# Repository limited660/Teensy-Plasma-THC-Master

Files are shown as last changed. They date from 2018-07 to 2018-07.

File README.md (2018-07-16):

# Teensy Plasma THC Master

Loop
- Teensy 3.1
  - CPU Speed : 96MHz
  - Optimize : Fastest with LTO
  - Loop Time : 5.5 microsecond average
  - Cost : $19.80 (7/15/2018)
- Teensy LC
  - CPU Speed : 48MHz
  - Optimize : Faster with LTO
  - Loop Time : 15.7 microsecond average
  - Cost : $11.65 (7/15/2018)

Screen
- RepRap Smart Controller (4x20 with Push Button Encoder)

Button
- One Press = Swap between Tip Target/Hysteresis & save value if changed
- Double Press = Recalls highlighted value from EEPROM
- Hold(Editing Value) = Saves highlighted value to EEPROM, this value is restored on power up and using Double Press
- Hold(Not Editing Value) = Disables output and voltage comparisions, still prints current tip voltage to screen (tip voltage is always printed with small delay) 

Encoder
- Change highlighted value

Frequency Counter
- THCAD should be set to F/1
- Gate interval of 10 milliseconds
- Change mapfloat in Loop to match numbers provided on THCAD

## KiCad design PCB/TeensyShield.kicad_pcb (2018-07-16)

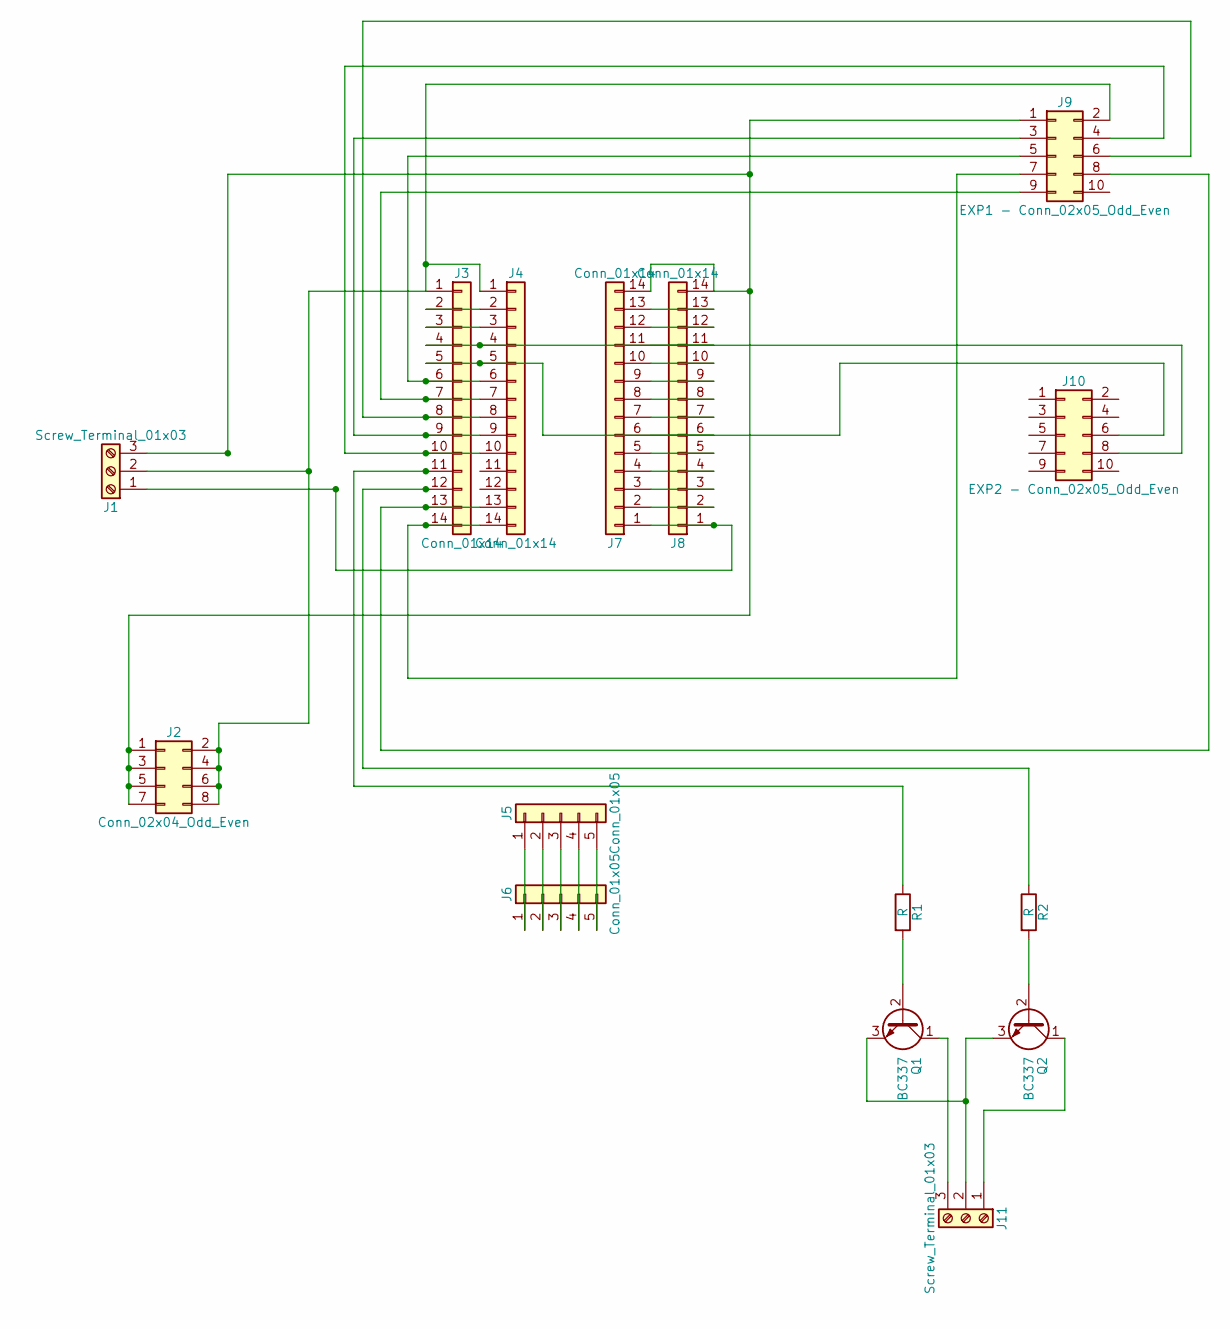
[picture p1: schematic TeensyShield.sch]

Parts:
J1, J11: Screw_Terminal_01x03; TerminalBlock_Phoenix_MPT-2.54mm_3pol
J2: Conn_02x04_Odd_Even; Pin_Header_Angled_2x04_Pitch2.54mm
J3, J4, J7, J8: Conn_01x14; Pin_Header_Straight_1x14_Pitch2.54mm
J5, J6: Conn_01x05; Pin_Header_Straight_1x05_Pitch2.54mm
J9: EXP1 - Conn_02x05_Odd_Even; Pin_Header_Straight_2x05_Pitch2.54mm
J10: EXP2 - Conn_02x05_Odd_Even; Pin_Header_Straight_2x05_Pitch2.54mm
Q1, Q2: BC337; TO-92_Molded_Narrow
R1, R2: R; R_Axial_DIN0207_L6.3mm_D2.5mm_P10.16mm_Horizontal

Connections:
unnamed: J1.1, J7.1, J8.1
unnamed: J1.2, J2.2, J2.4, J2.6, J2.8, J3.1, J4.1, J9.2
unnamed: J1.3, J2.1, J2.3, J2.5, J2.7, J7.14, J8.14, J9.1
unnamed: J3.2, J4.2
unnamed: J3.3, J4.3
unnamed: J3.6, J4.6, J9.5
unnamed: J3.7, J4.7, J9.9
unnamed: J3.8, J4.8, J9.6
unnamed: J3.9, J4.9, J9.3
unnamed: J3.10, J4.10, J9.4
unnamed: J3.11, R1.1
unnamed: J3.12, R2.1
unnamed: J3.13, J4.13, J9.8
unnamed: J3.14, J4.14, J9.7
unnamed: J5.1, J6.1
unnamed: J5.2, J6.2
unnamed: J5.3, J6.3
unnamed: J5.4, J6.4
unnamed: J5.5, J6.5
unnamed: J7.2, J8.2
unnamed: J7.3, J8.3
unnamed: J7.4, J8.4
unnamed: J7.5, J8.5
unnamed: J7.6, J8.6
unnamed: J7.7, J8.7
unnamed: J7.8, J8.8
unnamed: J7.9, J8.9
unnamed: J7.10, J8.10
unnamed: J7.11, J8.11
unnamed: J7.12, J8.12
unnamed: J7.13, J8.13
unnamed: J3.5, J4.5, J10.6
unnamed: J3.4, J4.4, J10.8
unnamed: J11.1, Q2.1 (C)
unnamed: J11.2, Q1.3 (E), Q2.3 (E)
unnamed: J11.3, Q1.1 (C)
unnamed: Q1.2 (B), R1.2
unnamed: Q2.2 (B), R2.2

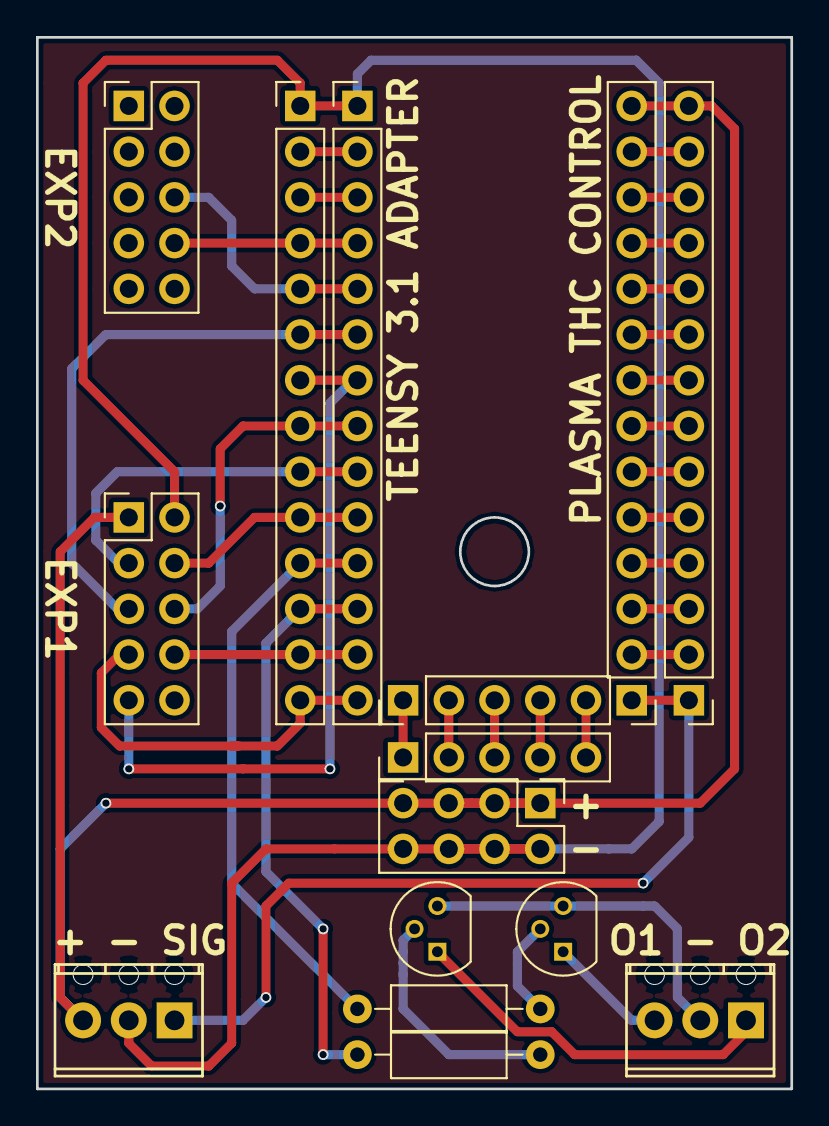
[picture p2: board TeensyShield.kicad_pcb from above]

Board: 2 copper layers, 41.9 x 58.4 mm, 15 parts (0 on the bottom side), 38 nets.

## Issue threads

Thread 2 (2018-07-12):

Height control fails to respond on fast voltage drop

limited660, 2018-07-12:
Voltage dropping below 100 disables outputs from Teensy causing torch crashes as head is no longer moving.  Placing a delay after moving to cut height and before allowed the voltage to stabilize enough for the Teensy to start outputting commands.  Hypertherm recommends 96v when cutting 12 Gauge with Powermax30 consumables at 30 amps which is the lowest found in the Powermax45 manual.

This may also require a rewrite on LCD and encoder printing to handle values less than 3 digits, code should be similar to Hysteresis printing.

Ideas:
Unlock floor to 50-75v?
Allow output 25-50v below/above target rather than hard floor/ceiling?

limited660, 2018-07-15:
Fixed in https://github.com/limited660/Teensy-Plasma-THC-Master/commit/e283efdac306a5a05f02b09cd5d4dcc160565763

Closed 2018-07-15.

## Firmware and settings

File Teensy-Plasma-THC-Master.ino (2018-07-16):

//Libraries
#include <FreqCount.h>
  //https://github.com/PaulStoffregen/FreqCount
#include <OneButton.h>
  //https://github.com/mathertel/OneButton
#include <LiquidCrystal.h>
#include <EEPROM.h>

//Floating Map Function
float mapfloat(float x, float in_min, float in_max, float out_min, float out_max)
{
  return (x - in_min) * (out_max - out_min) / (in_max - in_min) + out_min;
}

//THC A-D Input must be on pin 5 on Uno or pin 13 on Teensy 3.1
//OneButton pin needs swapped if changing between Uno and Teensy, pin 13 on Uno or pin 5 on Teensy 3.1

  //LCD Pins
  #define LCD_RS      12
  #define LCD_EN      11
  #define LCD_D4       6
  #define LCD_D5       4
  #define LCD_D6       8
  #define LCD_D7       7
  #define LCD_CHARS   20
  #define LCD_LINES    4

  //Encoder Pins
  int encoderPinA = 3;
  int encoderPinB = 2;

  //New OneButton
  OneButton button(5,true);

//LCD Pin Setup and Custom Character
LiquidCrystal lcd(LCD_RS, LCD_EN, LCD_D4, LCD_D5, LCD_D6, LCD_D7);
uint8_t testChar[8] = {0xff,0xff,0xff,0xff,0xff,0xff,0xff,0xff}; // Custom char


//Variable Setup
int16_t TargetVal, EncoderValue, TipEncoder, HysEncoder, TargetHys, PrevEncoder;
bool flash, thcStatus;
unsigned long startMillis, torchMillis, currentMillis;
float TorchVal, PrevTorch;
int ButtonPress, tUp, tDown, tOff, minVolt, maxVolt, lastEncoded;

void setup() {

  FreqCount.begin(10);
  
  //Variable setup
  flash = false;
  lastEncoded = 0;
  ButtonPress = 0;
  tUp = 0; 
  tDown = 0; 
  tOff = 0; 
  minVolt = 25;
  maxVolt = 175;
  
  
  TargetVal = EEPROM.read(0);
  TipEncoder = TargetVal;
  TargetHys = EEPROM.read(1);
  HysEncoder = TargetHys;

  thcStatus = EEPROM.read(2);
  
  EncoderValue = TipEncoder; //Start with TipEncoder since it is first in button statement
  
  //Timer setup
  startMillis = millis();
  torchMillis = millis();
  
  
  //Button setup
  button.attachClick(ClickFunction); //Create Click function for button
  button.attachDoubleClick(DoubleClickFunction); //Create Double Click function for button
  button.attachLongPressStart(HoldFunction); //Create Hold function for button
  
  
  //Output setup
  pinMode(9, OUTPUT); //Torch Up output
  digitalWrite(9, LOW); //Turn output off    
  pinMode(10, OUTPUT); //Torch Down output
  digitalWrite(10, LOW); //Turn output off
  
  
  //LCD Setup
  lcd.begin(LCD_CHARS, LCD_LINES);
  lcd.clear();
  lcd.createChar(0, testChar); //Create custom full block char and send to LCD
  
  
  //LCD startup message
  lcd.setCursor(0,0);
  lcd.print("CNC Plasma Torch");
  lcd.setCursor(0,1);
  lcd.print("Height Control");
  lcd.setCursor(0,2);
  lcd.print("Created by");
  lcd.setCursor(0,3);
  lcd.print("Tyler Bennett");
  delay(5000);
  lcd.clear();
  
  
  //LCD text setup
  lcd.setCursor(0, 0);
  lcd.print("Tip Voltage:");
  lcd.setCursor(13,0);
  lcd.print("-----");
  lcd.setCursor(0, 1);
  lcd.print("Tip Target:"); 
  lcd.setCursor(0, 2);
  lcd.print("Hysteresis:");
  if(thcStatus){
    lcd.setCursor(12, 1);
    lcd.print(TargetVal); //Write initial TargetVal, updated by button press
    lcd.setCursor(12, 2);
    lcd.print(TargetHys); //Write initial TargetHys, updated by button press
  }
  else {
    lcd.setCursor(12, 1);
    lcd.print("        ");
    lcd.setCursor(12, 2);
    lcd.print("        ");
    lcd.setCursor(12, 1);
    lcd.print("DISABLED");
    lcd.setCursor(12, 2);
    lcd.print("DISABLED");
  }
  lcd.setCursor(0,3);
  lcd.print("UP:");
  lcd.setCursor(6,3);
  lcd.print("Down:");
  lcd.setCursor(14,3);
  lcd.print("Off:");
  
  
  //Encoder Setup
  pinMode(encoderPinA, INPUT_PULLUP); 
  pinMode(encoderPinB, INPUT_PULLUP);
  
  //get starting position
  int lastMSB = digitalRead(encoderPinA);
  int lastLSB = digitalRead(encoderPinB);
  
  //let start be lastEncoded so will index on first click
  lastEncoded = (lastMSB << 1) |lastLSB;

}//Setup

void loop() {  

  currentMillis = millis(); //Grab current loop time, millis used to not delay code execution
  
  button.tick(); //Check button for input
  
  if (FreqCount.available()) {
    TorchVal = mapfloat(FreqCount.read(), 1197, 9265, 0.0, 10.0); //Mapping information from Mesa THCAD
    TorchVal = TorchVal*50; 
    if (currentMillis - torchMillis >= 250 && TorchVal != PrevTorch) { //Delay printing of TorchVal to make it easier to read and dont print if same as previous value
      torchMillis = millis();
      PrevTorch = TorchVal;
      lcd.setCursor(12,0);
      lcd.print("        ");
      lcd.setCursor(13,0);
      if (TorchVal < minVolt){ //Disable display below minVolt to signify no action
        lcd.print("------");
      } //End If
      else if (TorchVal > maxVolt){ //Disable display above maxVolt to signify no action
        lcd.setCursor(12,0);
        lcd.print("OVER-MAX");
      } //End If
      else{
        lcd.print(TorchVal,1);
      } //End Else
    } //End If
  } //End If
  
  if (ButtonPress == 1 || ButtonPress == 2) {
    int MSB = digitalRead(encoderPinA); //MSB = most significant bit
    int LSB = digitalRead(encoderPinB); //LSB = least significant bit
    int encoded = (MSB << 1) |LSB; //converting the 2 pin value to single number
    int sum  = (lastEncoded << 2) | encoded; //adding it to the previous encoded value
    if(sum == 0b1101 || sum == 0b0010)EncoderValue ++;  
    if(sum == 0b1110 || sum == 0b0001)EncoderValue --;
    lastEncoded = encoded; //store this value for next time
  } //End If
  
  if (ButtonPress == 1) {
    if(EncoderValue != TargetVal){
      if(EncoderValue <= minVolt)EncoderValue = minVolt; //Don't let EncoderValue below minVolt
      if(EncoderValue >= maxVolt)EncoderValue = maxVolt; //Don't let EncoderValue above maxVolt
      if(EncoderValue != PrevEncoder) {
        lcd.setCursor(12, 1);
        lcd.print("        ");
        lcd.setCursor(12, 1);
        lcd.print(EncoderValue);
        PrevEncoder = EncoderValue;
      } //End If
    } //End If
    else if(EncoderValue != PrevEncoder){
      lcd.setCursor(12, 1);
      lcd.print("        ");
      lcd.setCursor(12, 1);
      lcd.print(EncoderValue);
      PrevEncoder = EncoderValue;
    } //End Else If
    
    //Begin code for flashing Tip Target text
    if (currentMillis - startMillis >= 500 && flash) { //Hide Tip Target text
      startMillis = millis();
      lcd.setCursor(0, 1);
      lcd.print("           ");
      flash = false;
    } //End If
    else if(currentMillis - startMillis >= 300 && !flash) { //Show Tip Target text
      startMillis = millis();
      lcd.setCursor(0, 1);
      lcd.print("Tip Target:");
      flash = true;
    } //End Else If
  } //End If
  else if (ButtonPress ==2){
    if(EncoderValue != TargetHys){
      if(EncoderValue <= 0)EncoderValue = 0; //Don't let EncoderValue below 0
      if(EncoderValue >= 15)EncoderValue = 15; //Don't let EncoderValue above 15
      if(EncoderValue != PrevEncoder) {
        lcd.setCursor(12, 2);
        lcd.print("        ");
        lcd.setCursor(12, 2);
        lcd.print(EncoderValue);
        PrevEncoder = EncoderValue;
      } //End If
    } //End If
    else if(EncoderValue != PrevEncoder) {
      lcd.setCursor(12, 2);
      lcd.print("        ");
      lcd.setCursor(12, 2);
      lcd.print(EncoderValue);
      PrevEncoder = EncoderValue;
    } //End Else If
    
    //Begin code for flashing Tip Target text
    if (currentMillis - startMillis >= 500 && flash) { //Hide Tip Target text
      startMillis = millis();
      lcd.setCursor(0, 2);
      lcd.print("           ");
      flash = false;
    } //End If
    else if(currentMillis - startMillis >= 300 && !flash) { //Show Tip Target text
      startMillis = millis();
      lcd.setCursor(0, 2);
      lcd.print("Hysteresis:");
      flash = true;
    } //End Else If
  } //End Else If
  
  //Code for moving torch based on tip value compared to requested value, add outputs here.
  if(TorchVal < (TargetVal - TargetHys) && TorchVal >= minVolt && thcStatus){ //Voltage too low, raise torch     
    if(tUp != 1) { //Test if output has already been set
      //Turn Down off, Up on
      digitalWrite(10, LOW);       
      digitalWrite(9, HIGH);  
      tUp = 1; 
      tDown = 0; 
      tOff = 0; 
      lcd.setCursor(4,3);
      lcd.print((char)0);
      //Clear Other Squares
      lcd.setCursor(12,3);
      lcd.print(" ");
      lcd.setCursor(19,3);
      lcd.print(" ");
    } //End If
  } //End If
  else if(TorchVal > (TargetVal + TargetHys) && TorchVal <= maxVolt && thcStatus){ //Voltage too high, lower torch
    if(tDown != 1) { //Test if output has already been set
      //Turn Up off, Down on
      digitalWrite(9, LOW);       
      digitalWrite(10, HIGH); 
      tUp = 0; 
      tDown = 1; 
      tOff = 0; 
      lcd.setCursor(12,3);
      lcd.print((char)0);
      //Clear Other Squares
      lcd.setCursor(19,3);
      lcd.print(" ");
      lcd.setCursor(4,3);
      lcd.print(" ");
    } //End If
  } //End Else If
  else { //Voltage Stable - Outputs Off
    if(tOff != 1) { //Test if output has already been set
      //Turn both outputs off
      digitalWrite(10, LOW);       
      digitalWrite(9, LOW); 
      tUp = 0; 
      tDown = 0; 
      tOff = 1; 
      lcd.setCursor(19,3);
      lcd.print((char)0);
      //Clear Other Squares
      lcd.setCursor(4,3);
      lcd.print(" ");
      lcd.setCursor(12,3);
      lcd.print(" ");
    } //End If
  } //End Else

}// Loop

  
void ClickFunction() { //Runs on single click of encoder button
  if(thcStatus){
    if(ButtonPress == 3)ButtonPress = 0; //Loop back around
    
    if(ButtonPress == 1){
      if(EncoderValue != TargetVal){//Encoder was changed, 
        TargetVal = EncoderValue;
        TipEncoder = EncoderValue;
        ButtonPress = -1;
        lcd.setCursor(12, 1);
        lcd.print("        ");
        lcd.setCursor(12, 1);
        lcd.print(TargetVal);
      }
      else {
        EncoderValue = HysEncoder; //Swap to HysEncoder so it is ready for next button press
        lcd.setCursor(12, 1);
        lcd.print("        ");
        lcd.setCursor(12, 1);
        lcd.print(TargetVal);
      }
    }
    
    if(ButtonPress == 2){   
      if(EncoderValue != TargetHys){
        TargetHys = EncoderValue;
        HysEncoder = EncoderValue;
        ButtonPress = -1;
        lcd.setCursor(12, 2);
        lcd.print("        ");
        lcd.setCursor(12, 2);
        lcd.print(TargetHys);
      }
      else {
        lcd.setCursor(12, 2);
        lcd.print("        ");
        lcd.setCursor(12, 2);
        lcd.print(TargetHys);
      }
      EncoderValue = TipEncoder;
    }
    //Write back to LCD in case lines were blank when exiting flashing statement
    lcd.setCursor(0, 1);
    lcd.print("Tip Target:");
    lcd.setCursor(0, 2);
    lcd.print("Hysteresis:");
    ButtonPress++;
  }
}

void DoubleClickFunction() { //Runs on double click of encoder button
  if(ButtonPress == 1) {
    EncoderValue = EEPROM.read(0);
    lcd.setCursor(12, 1);
    lcd.print("        ");
    lcd.setCursor(12, 1);
    lcd.print(EncoderValue);
  }
  if(ButtonPress == 2) {
    EncoderValue = EEPROM.read(1);
    lcd.setCursor(12, 2);
    lcd.print("        ");
    lcd.setCursor(12, 2);
    lcd.print(EncoderValue);
  }
}

void HoldFunction() { //Runs on hold of encoder button
  if(ButtonPress == 1) {
    EEPROM.write(0, TargetVal); //Write current TargetVal to EEPROM 0
    lcd.setCursor(12, 1);
    lcd.print("        ");
    lcd.setCursor(12, 1);
    lcd.print("SAVED");
  }
  else if(ButtonPress == 2) {
    EEPROM.write(1, TargetHys); //Write current TargetHys to EEPROM 1
    lcd.setCursor(12, 2);
    lcd.print("        ");
    lcd.setCursor(12, 2);
    lcd.print("SAVED");
  }
  else {
    if (thcStatus) {
      thcStatus = false;
      lcd.setCursor(12, 1);
      lcd.print("        ");
      lcd.setCursor(12, 2);
      lcd.print("        ");
      lcd.setCursor(12, 1);
      lcd.print("DISABLED");
      lcd.setCursor(12, 2);
      lcd.print("DISABLED");
      EEPROM.write(2, thcStatus); //Write current thcStatus to EEPROM 2
    }
    else{
      thcStatus = true;
      lcd.setCursor(12, 1);
      lcd.print("        ");
      lcd.setCursor(12, 2);
      lcd.print("        ");
      lcd.setCursor(12, 1);
      lcd.print(TargetVal);
      lcd.setCursor(12, 2);
      lcd.print(TargetHys);
      EEPROM.write(2, thcStatus); //Write current thcStatus to EEPROM 2
    }
  }
}

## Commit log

2018-07-12 Testing of code successful, loop time down to 7-12 microseconds on Teensy 3.1 (#1)
    Testing of code successful, loop time down to 7-12 microseconds on Teensy 3.1
2018-07-14 Min/Max Volt Changes, Cleanup
    - Added minVolt and maxVolt variables
    - Extended working range of output to prevent head crashes
    - Removed unused variables
    - Removed all serial and code timing
    - Added library link for FreqCount
    - Added message for over voltage to signify output is off
    [Teensy-Plasma-THC-Master.ino]
2018-07-15 Added button function to disable outputs
    Added function to button hold to disable outputs if ButtonPress is not 1 or 2 (not editing a value), it will print "DISABLED" on Tip Target and Hysteresis, turn outputs off, and write status to EEPRO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
2018-07-16 Fixed LCD blanking when using save
    Fixed a problem where screen would not clear "SAVED" text after saving a value, changing the value using the encoder, and then applying that value.
    [Teensy-Plasma-THC-Master.ino]
2018-07-16 KICAD PCB Files
    [TeensyShield.kicad_pcb, TeensyShield.sch]
2018-07-16 Moved output toggling before if statement
    Moved toggling to prevent extra cycles if output already switched
    [Teensy-Plasma-THC-Master.ino]
